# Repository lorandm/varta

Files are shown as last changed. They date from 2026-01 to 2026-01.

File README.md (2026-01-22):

# VARTA - Open Source Acoustic Drone Detector

**V**isual and **A**coustic **R**eal-**T**ime **A**lert System



[]()

---

> ⚠️ **ALPHA STATUS - READ BEFORE PROCEEDING**
>
> This project provides a **complete framework** for building an acoustic drone detector, but it is **not a plug-and-play solution**. Before this device will detect anything, you must:
>
> 1. **Collect training data** - Record drone audio samples in your environment
> 2. **Train the ML model** - Run the training pipeline on your collected data
> 3. **Assemble hardware** - Build the device from components (~$80-100)
> 4. **Calibrate and test** - Tune detection thresholds for your conditions
>
> **Current limitations:**
> - No pre-trained model included (you must train your own)
> - 4-microphone simultaneous capture needs firmware work (currently single-mic)
> - Detection performance is theoretical until field-validated
> - Hardware design is breadboard-ready, not a finished PCB
>
> This project is ideal for makers, researchers, and defense engineers who can contribute to development. It is **not ready** for non-technical end users expecting a finished product.
>
> **We welcome contributions** - especially training data, field test results, and firmware improvements.

---

## Overview

VARTA is an open-source, portable acoustic drone detection system designed to detect fiber optic controlled FPV drones that evade traditional RF-based detectors. Built for under $100 in components, it provides early warning capability for personnel in the field.

**Why VARTA exists:** RF drone detectors (like the BlueBird Chuyka) cannot detect fiber optic controlled drones because these drones don't emit radio signals. VARTA fills this critical gap using acoustic detection.

## Key Features

- **4-microphone beamforming array** for direction estimation
- **ML-based detection** using TensorFlow Lite for edge inference
- **4-8 second detection** at 200-500m range (environment dependent)
- **Visual + haptic + audio alerts** for high-noise environments
- **8+ hours battery life** on 2S 18650 pack
- **IP54 rated enclosure** (3D printable)
- **$80-100 total BOM cost**

## Specifications

| Parameter | Value |
|---|---|
| Detection Range | 200-500m (line of sight, low ambient noise) |
| Detection Time | 4-8 seconds |
| Direction Accuracy | ±15° azimuth |
| Power Supply | 7.4V (2S 18650) |
| Battery Life | 8+ hours continuous |
| Operating Temp | -20°C to +50°C |
| Enclosure Rating | IP54 |
| Weight | ~350g with battery |
| Dimensions | 140 x 80 x 45 mm |

## How It Works

### Detection Principle

Drone motors produce distinctive acoustic signatures in the 100-1000Hz range with characteristic harmonic patterns. VARTA uses:

1. **FFT Analysis** - Continuous spectral analysis looking for drone motor fundamentals (typically 150-400Hz) and their harmonics
2. **Beamforming** - Time-difference-of-arrival (TDOA) across 4 microphones estimates threat direction
3. **ML Classification** - TensorFlow Lite model distinguishes drones from environmental noise (vehicles, wind, wildlife)

### Limitations

- **Range decreases significantly** in high ambient noise (combat, vehicles, wind)
- **Cannot detect** drones with silenced/baffled motors at useful range
- **False positives** possible from other small motors, insects, etc.
- **No altitude estimation** - only azimuth direction
- **Requires line-of-sight acoustically** - terrain/structures block sound

## Hardware

### Bill of Materials

| Component | Quantity | Unit Cost | Notes |
|---|---|---|---|
| ESP32-S3-WROOM-1 | 1 | $8 | N16R8 variant recommended |
| INMP441 MEMS Microphone | 4 | $3 | I2S output |
| 0.96" OLED Display (SSD1306) | 1 | $4 | I2C, 128x64 |
| 2.4" TFT Display (ILI9341) | 1 | $8 | SPI, optional for waveform |
| Piezo Buzzer | 1 | $1 | 3-5V active |
| Vibration Motor | 1 | $2 | 3V coin type |
| WS2812B LED Ring (8 LED) | 1 | $3 | Direction indicator |
| 18650 Battery Holder (2S) | 1 | $3 | With BMS |
| 18650 Cells | 2 | $8 | 2500mAh+ recommended |
| TP4056 Charger Module | 1 | $1 | USB-C preferred |
| MT3608 Boost Converter | 1 | $1 | 5V for ESP32 |
| Power Switch | 1 | $1 | SPST |
| SMA Connectors (optional) | 4 | $4 | For external mics |
| PCB (custom) | 1 | $10 | JLCPCB/PCBWay |
| 3D Printed Enclosure | 1 | $5 | PLA or PETG |
| Misc (wires, screws, etc.) | - | $5 | - |

**Total: ~$85**

### Microphone Array Geometry

The 4 microphones are arranged in a square pattern with 50mm spacing:

```
        Front
          ↑
    [M1]-----[M2]
      |       |
      |   ●   |    ● = center/mounting point
      |       |
    [M4]-----[M3]
    
    Spacing: 50mm between adjacent mics
```

This geometry allows:
- Azimuth estimation via TDOA
- Reasonable angular resolution (~15°)
- Compact form factor

### Schematic

See `/hardware/kicad/` for full KiCad project files.

Key connections:
- **Microphones (I2S)**: All 4 INMP441 share SCK (GPIO14) and WS (GPIO15), individual SD pins (GPIO4, 5, 6, 7)
- **OLED Display (I2C)**: SDA (GPIO21), SCL (GPIO22)
- **TFT Display (SPI)**: MOSI (GPIO23), SCK (GPIO18), CS (GPIO5), DC (GPIO16), RST (GPIO17)
- **LED Ring**: Data (GPIO48)
- **Buzzer**: GPIO38
- **Vibration Motor**: GPIO39

## Firmware

### Building

Requires PlatformIO:

```bash
cd firmware
pio run
pio run --target upload
```

### Configuration

Edit `include/config.h`:

```c
// Detection thresholds (adjust based on field testing)
#define DETECTION_THRESHOLD_DB    65.0f   // Minimum signal level
#define CONFIDENCE_THRESHOLD      0.75f   // ML model confidence
#define ALERT_HOLDOFF_MS          2000    // Debounce alerts

// Hardware config
#define MIC_SPACING_MM            50.0f   // Physical mic spacing
#define SAMPLE_RATE               44100   // Audio sample rate
#define FFT_SIZE                  2048    // FFT window size
```

### Operating Modes

1. **SCAN** (default) - Continuous monitoring, LED ring shows ambient level
2. **ALERT** - Threat detected, LED shows direction, buzzer + vibration active
3. **MONITOR** - Display shows real-time spectrogram (debugging)
4. **CALIBRATE** - Ambient noise profiling for location

Button controls:
- **Short press**: Cycle display modes
- **Long press (3s)**: Enter calibration mode
- **Double press**: Mute audio alerts (haptic remains)

## Machine Learning

### Model Architecture

Lightweight CNN designed for ESP32-S3:

```
Input: 128 mel-frequency bands x 32 time frames (1 second)
├── Conv2D(16, 3x3) + ReLU + MaxPool
├── Conv2D(32, 3x3) + ReLU + MaxPool
├── Conv2D(64, 3x3) + ReLU + GlobalAvgPool
├── Dense(32) + ReLU + Dropout(0.3)
└── Dense(2) + Softmax → [no_drone, drone]

Parameters: ~45,000
Inference time: ~50ms on ESP32-S3
```

### Training Your Own Model

The default model provides baseline detection. For best results, train on data from your operational environment:

```bash
cd ml/training

# 1. Collect audio samples
python collect_samples.py --device your_mic --duration 300

# 2. Label samples (creates labels.csv)
python labeler.py --input samples/

# 3. Train model
python train.py --data samples/ --labels labels.csv --epochs 100

# 4. Convert to TFLite
python convert_tflite.py --model checkpoints/best.h5 --output ../models/

# 5. Generate C header for firmware
xxd -i models/drone_detector.tflite > ../firmware/src/model_data.h
```

### Training Data Requirements

For effective detection, collect:
- **Positive samples**: Various drone types at different distances/angles
- **Negative samples**: Environmental noise from deployment location
  - Wind, foliage rustling
  - Distant vehicles, aircraft
  - Voices, footsteps
  - Wildlife (birds, insects)
  - Combat sounds (if applicable)

Recommended: 2+ hours of each class, diverse conditions.

## Enclosure

### 3D Printing

Files in `/enclosure/`:
- `varta_body.stl` - Main enclosure
- `varta_lid.stl` - Top cover with mic ports
- `varta_clip.stl` - Belt/MOLLE clip

Print settings:
- Material: PETG recommended (better temperature resistance than PLA)
- Layer height: 0.2mm
- Infill: 20%
- Supports: Yes (for mic port overhangs)

### Weatherproofing

For IP54 rating:
1. Apply silicone sealant to lid seam
2. Install acoustic vent membrane over mic ports (e.g., Gore-Tex patch)
3. Seal cable glands with silicone

## Assembly

See [docs/ASSEMBLY.md](docs/ASSEMBLY.md) for step-by-step instructions with photos.

Quick overview:
1. Solder microphones to breakout boards (or direct to PCB)
2. Assemble main PCB with ESP32, power management
3. Wire display, buzzer, vibration motor
4. Install battery holder and cells
5. Mount PCB in enclosure
6. Position microphones in lid at correct spacing
7. Final wiring and close-up
8. Flash firmware and calibrate

## Field Use

### Pre-deployment

1. Power on and wait for self-test (LED sequence)
2. Verify GPS fix if equipped (optional module)
3. Run calibration in deployment location (30 seconds)
4. Verify alert function with test tone

### Operational Notes

- **Position**: Wear on shoulder/chest, mics facing likely threat direction
- **Ambient noise**: Detection range decreases significantly with background noise
- **Terrain**: Hills, buildings, vegetation attenuate sound - adjust expectations
- **Weather**: Wind is the enemy - seek shelter or accept reduced range
- **False alarms**: Initial deployments will have false positives; re-train model with local data

### Interpreting Alerts

LED ring indicates estimated threat direction:
- **Red LED position**: Threat azimuth (north = front, clockwise)
- **LED brightness**: Signal strength / confidence
- **Pulsing**: Active threat
- **Solid**: Recent detection, threat may have passed

## Roadmap

### Current Status (v0.1-alpha)

| Component | Status | Notes |
|---|---|---|
| Firmware architecture | ✅ Complete | Compiles, structured for expansion |
| Single-mic detection | ✅ Working | Basic audio capture and FFT |
| 4-mic simultaneous | 🔧 Partial | Needs I2S TDM implementation |
| Direction estimation | 🔧 Partial | Algorithm ready, needs 4-mic hardware |
| ML training pipeline | ✅ Complete | Collect, label, train, convert |
| Pre-trained model | ❌ Missing | Requires drone audio recordings |
| 3D enclosure | ✅ Complete | Parametric OpenSCAD source |
| Custom PCB | ❌ Not started | Current design uses dev boards |
| Field validation | ❌ Not done | No real-world test data yet |

### Priority Contributions Needed

1. **Training data** - Drone recordings at various distances/conditions
2. **4-channel I2S** - ESP32-S3 TDM mode or multi-I2S implementation  
3. **Field testing** - Build one, test it, report results
4. **PCB design** - Single board replacing dev board stack

### Future Ideas

- Bluetooth app for configuration and alerts
- Mesh networking between multiple units
- Integration with camera/thermal systems
- Solar power option for fixed installations
- LoRa for long-range alerting

## Contributing

Contributions welcome! Priority areas:
- Improved ML models trained on diverse drone types
- Alternative microphone arrays (linear, larger aperture)
- Integration with other sensor systems
- Mobile app for configuration/visualization
- Power optimization

See [CONTRIBUTING.md](CONTRIBUTING.md) for guidelines.

## License

Hardware: CERN-OHL-P-2.0
Software: MIT
Documentation: CC-BY-4.0

## Acknowledgments

This project builds on:
- ESP-IDF and Arduino frameworks
- TensorFlow Lite for Microcontrollers
- Countless open source audio processing libraries

## Disclaimer

VARTA is provided as-is for educational and research purposes. Detection performance varies significantly based on environmental conditions, drone types, and deployment scenario. This device is not a substitute for other protective measures. The authors assume no liability for use in any context.

---

*"In war, let your great object be victory, not lengthy campaigns."* - Sun Tzu

Built with urgency for those who need it.

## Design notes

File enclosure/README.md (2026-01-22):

# VARTA Enclosure

3D printable enclosure for the acoustic drone detector.

## Files

| File | Description |
|---|---|
| `enclosure.scad` | Parametric OpenSCAD source |
| `varta_body.stl` | Main body (pre-generated) |
| `varta_lid.stl` | Top cover with mic ports |
| `varta_clip.stl` | Belt/MOLLE attachment clip |

## Generating STL Files

If you need to modify the design, edit `enclosure.scad` and regenerate:

```bash
# Install OpenSCAD first
# Ubuntu: sudo apt install openscad
# Mac: brew install openscad

# Generate all parts
openscad -o varta_body.stl -D 'part="body"' enclosure.scad
openscad -o varta_lid.stl -D 'part="lid"' enclosure.scad  
openscad -o varta_clip.stl -D 'part="clip"' enclosure.scad
```

## Print Settings

### Recommended Settings

| Parameter | Value |
|---|---|
| Material | PETG (preferred) or PLA |
| Layer Height | 0.2mm |
| Infill | 20% |
| Perimeters | 3 |
| Top/Bottom Layers | 4 |
| Supports | Yes (for mic port overhangs) |

### Material Notes

**PETG** (Recommended)
- Better temperature resistance (-20°C to +70°C)
- More impact resistant
- Slight flexibility reduces cracking
- Harder to print (stringing)

**PLA**
- Easier to print
- More rigid
- Lower temperature tolerance (<50°C)
- Can warp in hot environments

**ABS**
- Good temperature resistance
- Requires enclosed printer
- More post-processing (fumes, warping)

## Assembly

### Hardware Needed

| Item | Quantity | Notes |
|---|---|---|
| M3 x 8mm screws | 4 | Lid attachment |
| M3 x 6mm screws | 4 | PCB mounting |
| M2 x 4mm screws | 4 | Mic board mounting |
| M3 nuts | 4 | For clip attachment |
| Silicone gasket (optional) | 1 | For IP54 sealing |

### Assembly Steps

1. **Prepare body**
   - Clean up any support material
   - Check screw boss threads (may need to tap)

2. **Install PCB standoffs**
   - Insert M3 screws from inside
   - Secure PCB with additional nuts or use self-tapping screws

3. **Mount components in lid**
   - Position microphone boards over ports
   - Secure with M2 screws
   - Install display bezel (if using)
   - Install LED ring

4. **Wire everything**
   - Connect microphones to main PCB
   - Connect display, LEDs, buzzer, vibration motor
   - Install battery holder

5. **Final assembly**
   - Apply silicone gasket to lid edge (optional)
   - Close lid and secure with M3 screws
   - Attach belt clip if needed

## Weatherproofing (IP54)

For outdoor use, add weatherproofing:

1. **Lid seal**
   - Apply 2mm silicone gasket to lid edge
   - Or use RTV silicone sealant

2. **Microphone ports**
   - Install acoustic vent membranes (e.g., GORE-TEX patches)
   - These allow sound through while blocking water
   - Available from speaker repair suppliers

3. **Display window**
   - Install clear acrylic or polycarbonate window
   - Seal edges with silicone

4. **USB port**
   - Install rubber plug when not charging
   - Or use waterproof USB connector

## Customization

### Key Parameters in OpenSCAD

```openscad
// Adjust these to fit your components:

mic_spacing = 50;       // Distance between mics
mic_hole_dia = 8;       // INMP441 breakout size
oled_width = 28;        // Display cutout
led_ring_dia = 32;      // LED ring size

// Overall size:
body_length = 140;
body_width = 80;
body_height = 35;
```

### Adding Features

To add new cutouts or mounting points:

1. Open `enclosure.scad` in OpenSCAD
2. Find the `body()` or `lid()` module
3. Add `translate()` and primitive shapes
4. Use `difference()` for cutouts
5. Preview and export STL

### Alternative Mounting Options

**Helmet mount**
- Design a curved plate to match helmet profile
- Use Velcro or screw attachment

**Vehicle mount**
- Add suction cup or magnetic base
- Consider vibration damping

**Pole mount**
- Design clamp attachment
- Good for perimeter monitoring

## Troubleshooting

### Parts Don't Fit

- Check `fit_tolerance` parameter (default 0.3mm)
- Your printer may need different value
- Print a test piece first

### Mic Ports Wrong Size

- Measure your actual breakout boards
- Adjust `mic_hole_dia` and `mic_mount_dia`

### Screws Don't Thread

- May need to tap holes with M3 tap
- Or use self-tapping screws
- Or heat-set inserts (recommended)

### Water Ingress

- Check gasket seating
- Verify acoustic membranes are installed
- Apply additional sealant to seams

## License

CERN-OHL-P-2.0 (Permissive Open Hardware License)

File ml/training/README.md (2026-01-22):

# VARTA ML Training Pipeline

This directory contains everything needed to train your own drone detection model.

## Requirements

```bash
pip install -r requirements.txt
```

## Quick Start

### 1. Collect Audio Samples

Record audio in environments where you'll deploy the detector:

```bash
# List available microphones
python collect_samples.py --list-devices

# Record for 5 minutes (press SPACE when you hear a drone)
python collect_samples.py --device 0 --duration 300 --output samples/
```

**Tips for good training data:**
- Record in actual deployment locations
- Include various distances (50m, 100m, 200m, 500m)
- Record different times of day (temperature affects sound propagation)
- Include various "negative" sounds: wind, vehicles, voices, wildlife
- Mark drone segments in real-time for accurate labels

### 2. Label Samples (if needed)

If you have unlabeled audio files, use the interactive labeler:

```bash
python labeler.py --input samples/

# Check labeling progress
python labeler.py --input samples/ --stats
```

### 3. Train Model

```bash
python train.py \
    --data samples/ \
    --labels samples/labels.csv \
    --epochs 100 \
    --output output/
```

Training will:
- Split data into train/val/test sets
- Train a lightweight CNN
- Save best model to `output/checkpoints/best.h5`
- Generate classification report

### 4. Convert to TFLite

```bash
python convert_tflite.py \
    --model output/checkpoints/best.h5 \
    --output ../models/ \
    --generate-header
```

This creates:
- `drone_detector_quant.tflite` - Quantized model for ESP32
- `model_data.h` - C header for firmware

### 5. Update Firmware

Copy the generated header to the firmware:

```bash
cp ../models/model_data.h ../firmware/src/model_data.h
```

Rebuild and flash:

```bash
cd ../firmware
pio run
pio run --target upload
```

## Training Data Guidelines

### Positive Samples (Drones)

Record various drone types at different distances and angles:

| Drone Type | Distance | Samples Needed |
|---|---|---|
| FPV racing | 50-200m  | 200+ segments  |
| FPV camera | 50-500m  | 200+ segments  |
| DJI-style  | 100-500m | 100+ segments  |

### Negative Samples (Not Drones)

Critical for reducing false positives:

| Sound Source | Samples Needed |
|---|---|
| Wind/foliage | 300+ segments  |
| Vehicles | 200+ segments  |
| Aircraft | 100+ segments  |
| Voices | 100+ segments  |
| Wildlife | 100+ segments  |
| Silence | 100+ segments  |
| Combat sounds| 200+ segments  |

### Data Augmentation

The training script applies automatic augmentation:
- Time shifting
- Noise injection
- Pitch shifting
- Time stretching

This helps with generalization but doesn't replace diverse real-world data.

## Model Architecture

The default model is a lightweight CNN designed for ESP32-S3:

```
Input: (32, 128, 1) - 32 time frames × 128 mel bins

Conv2D(16) → BatchNorm → ReLU → MaxPool
Conv2D(32) → BatchNorm → ReLU → MaxPool
Conv2D(64) → BatchNorm → ReLU → GlobalAvgPool
Dense(32) → ReLU → Dropout(0.3)
Dense(2) → Softmax

Total parameters: ~45,000
Inference time: ~50ms on ESP32-S3
```

## Customization

### Adjusting Detection Sensitivity

In `train.py`, modify:

```python
SAMPLE_RATE = 44100    # Match your hardware
N_MELS = 128           # Frequency resolution
DURATION = 1.0         # Detection window (seconds)
```

### Different Model Architectures

For better accuracy (larger model):
- Add more conv layers
- Increase filter counts
- Use attention mechanisms

For faster inference (smaller model):
- Reduce filter counts
- Use depthwise separable convolutions
- Decrease input resolution

### Transfer Learning

Start from a pre-trained audio model:

```python
# In train.py
from tensorflow.keras.applications import MobileNetV2

base_model = MobileNetV2(
    input_shape=(128, 128, 1),
    include_top=False,
    weights=None  # or use imagenet and adapt
)
```

## Troubleshooting

### Low Accuracy

- More training data needed (especially negatives)
- Try longer training (more epochs)
- Check class balance in dataset
- Verify audio quality (no clipping, correct sample rate)

### High False Positive Rate

- Add more negative samples from deployment environment
- Increase detection threshold in firmware
- Use multiple consecutive detections before alerting

### Model Too Large

- Enable quantization (default)
- Reduce model complexity
- Decrease input resolution (fewer mel bins)

### Inference Too Slow

- Use int8 quantization
- Reduce model depth
- Optimize ESP32-S3 settings (CPU frequency, etc.)

## Files

| File | Description |
|---|---|
| `collect_samples.py` | Real-time audio recording with marking |
| `labeler.py` | Interactive sample labeling tool |
| `train.py` | Model training script |
| `convert_tflite.py` | TFLite conversion for ESP32 |
| `requirements.txt` | Python dependencies |

## License

MIT License - see main project LICENSE

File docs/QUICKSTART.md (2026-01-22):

# VARTA Quick Start Guide

Get your acoustic drone detector running in under 2 hours.

## Prerequisites

**Tools needed:**
- Soldering iron
- Wire strippers
- Small screwdrivers
- 3D printer (or order prints)

**Software:**
- PlatformIO (VS Code extension or CLI)
- Python 3.8+ (for ML training)

## Step 1: Order Parts (5 minutes)

Order from the BOM in `/hardware/bom/BOM.csv`. Key items:
- ESP32-S3-DevKitC-1 (~$10)
- 4x INMP441 microphones (~$12)
- SSD1306 OLED display (~$4)
- WS2812B 8-LED ring (~$3)
- 2S 18650 battery pack (~$12)
- Power management boards (~$4)

**Total: ~$85**

## Step 2: Print Enclosure (2-4 hours)

Print from `/enclosure/` with PETG:
```bash
# Generate STLs if needed
openscad -o varta_body.stl -D 'part="body"' enclosure.scad
openscad -o varta_lid.stl -D 'part="lid"' enclosure.scad
```

Settings: 0.2mm layers, 20% infill, supports on.

## Step 3: Assemble (1-2 hours)

See `/docs/ASSEMBLY.md` for detailed instructions. Quick version:

1. **Power system:**
   - Battery holder → TP4056 charger → power switch → MT3608 boost (set to 5V) → ESP32

2. **Microphones:**
   - Wire all 4 INMP441 boards to shared I2S bus (SCK=GPIO14, WS=GPIO15)
   - Individual data lines to GPIO4, 5, 6, 7
   - Mount in lid with 50mm spacing

3. **Peripherals:**
   - OLED: SDA=GPIO21, SCL=GPIO22
   - LED ring: Data=GPIO48
   - Buzzer: GPIO38
   - Button: GPIO0

4. **Final assembly:**
   - Mount PCB in body
   - Connect all wiring
   - Install lid

## Step 4: Flash Firmware (5 minutes)

```bash
cd firmware
pip install platformio
pio run --target upload
pio device monitor  # Verify startup
```

You should see:
```
=== VARTA Acoustic Drone Detector ===
Initializing...
Initialization complete. Entering SCAN mode.
```

## Step 5: Calibrate (1 minute)

1. Power on device
2. Take to deployment location
3. Long-press button (3 seconds)
4. Wait 30 seconds for calibration
5. Done!

## Step 6: Train Custom Model (Optional, 1+ hours)

For best results, train on local audio:

```bash
cd ml/training
pip install -r requirements.txt

# Collect samples (press SPACE when drone present)
python collect_samples.py --device 0 --duration 300

# Train model
python train.py --data samples/ --labels samples/labels.csv --epochs 100

# Convert for ESP32
python convert_tflite.py --model output/checkpoints/best.h5 --output ../models/ --generate-header

# Update firmware
cp ../models/model_data.h ../firmware/src/model_data.h
cd ../firmware && pio run --target upload
```

## Usage

**Display modes:**
- SCAN: Normal monitoring (blue LED breathing)
- ALERT: Threat detected (red LED shows direction)
- MONITOR: Debug spectrogram view

**Controls:**
- Short press: Cycle display modes
- Double press: Mute audio (haptic only)
- Long press (3s): Calibration mode

**LED ring:**
- Blue breathing: Scanning
- Red direction: Threat detected (north = front)

## Troubleshooting

**No power:** Check battery, switch, boost converter output (should be 5V)

**Display blank:** Verify I2C address (0x3C or 0x3D), check wiring

**No detection:** Recalibrate in deployment location, check mic connections

**Too many false alarms:** Train custom model with local noise samples

## Need Help?

- Full docs: `/docs/ASSEMBLY.md`
- ML training: `/ml/training/README.md`
- Issues: GitHub Issues

---

*Built with urgency for those who need it.*

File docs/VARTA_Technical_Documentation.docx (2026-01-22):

VARTA

Visual and Acoustic Real-Time Alert System

Open Source Portable Acoustic Drone Detector

Designed to detect fiber optic controlled FPV drones

that evade traditional RF-based detection systems

Technical Documentation v1.0

January 2025

Hardware: CERN-OHL-P-2.0 | Software: MIT | Docs: CC-BY-4.0

# Table of Contents

# Executive Summary

VARTA is an open-source, portable acoustic drone detection system designed to address a critical gap in current drone defense: the inability of RF-based detectors to identify fiber optic controlled drones.

Traditional drone detection systems like the BlueBird Chuyka rely on detecting radio frequency emissions from drone control links. However, fiber optic controlled FPV drones transmit no RF signals, making them invisible to these systems. VARTA fills this gap using acoustic detection and machine learning classification.

## Key Capabilities

- 4-microphone beamforming array for direction estimation
- Machine learning classification using TensorFlow Lite on edge
- 200-500m detection range (environment dependent)
- Visual, audio, and haptic alerts for high-noise environments
- $80-100 total bill of materials cost
- Fully open source hardware and software

## Target Users

Infantry units, security personnel, and defensive operators who need portable, low-cost early warning against fiber optic FPV drones where RF detection is ineffective.

# Problem Statement

## The Fiber Optic Drone Threat

Fiber optic controlled FPV drones represent a significant evolution in drone warfare. By transmitting video and control signals through a thin fiber optic cable rather than radio waves, these systems achieve:

- Complete immunity to RF jamming and detection
- Zero electromagnetic signature during flight
- High-bandwidth, low-latency video transmission
- Resistance to electronic warfare countermeasures

## Current Detection Gap

RF-based drone detectors like the BlueBird Chuyka 2.0 ($460, 900-1800 MHz and 4860-6060 MHz scanning) are completely ineffective against fiber optic drones because there are no radio signals to detect.

Military-grade solutions exist (radar, sensor fusion) but are expensive ($50,000+), vehicle-mounted, and unavailable to frontline infantry units who face the most immediate threat.

## Market Opportunity

There is no commercially available portable detector in the $1,000-3,000 price range that can detect fiber optic drones. VARTA fills this gap using acoustic detection, the only viable passive detection method for infantry-portable systems.

# Technical Specifications

## System Overview

Parameter | Specification
Detection Range | 200-500m (line of sight, low ambient noise)
Detection Time | 4-8 seconds
Direction Accuracy | ±15° azimuth
Power Supply | 7.4V (2S 18650 Li-Ion)
Battery Life | 8+ hours continuous
Operating Temperature | -20°C to +50°C
Enclosure Rating | IP54 (dust and splash protected)
Weight | ~350g with battery
Dimensions | 140 x 80 x 45 mm

## Detection Methodology

VARTA uses three complementary detection techniques:

1. FFT Spectral Analysis: Continuous fast Fourier transform analysis identifies drone motor fundamentals (typically 150-400 Hz) and their characteristic harmonic patterns.

2. Beamforming: Time-difference-of-arrival (TDOA) across the 4-microphone square array estimates threat direction with ±15° accuracy.

3. ML Classification: A lightweight convolutional neural network running on the ESP32-S3 distinguishes drone signatures from environmental noise (vehicles, wind, wildlife).

## Hardware Architecture

The system is built around the ESP32-S3-WROOM-1 microcontroller with integrated Wi-Fi and Bluetooth, 16MB flash, and 8MB PSRAM for ML inference.

Component | Specification | Purpose
ESP32-S3-WROOM-1-N16R8 | 240 MHz dual-core, 16MB flash | Main processor, ML inference
INMP441 MEMS Microphone | I2S digital output, 4 units | Audio capture
SSD1306 OLED | 128x64 pixels, I2C | Status display
WS2812B LED Ring | 8 LEDs, 32mm diameter | Direction indicator
Piezo Buzzer | 3-5V active | Audio alert
Coin Vibration Motor | 3V DC | Haptic alert
18650 2S Pack | 7.4V, 5000mAh | Power source

# Machine Learning Model

## Architecture

The detection model is a lightweight convolutional neural network optimized for real-time inference on the ESP32-S3:

Input: 128 mel-frequency bands × 32 time frames (1 second of audio)

Layer 1: Conv2D (16 filters, 3×3) + BatchNorm + ReLU + MaxPool

Layer 2: Conv2D (32 filters, 3×3) + BatchNorm + ReLU + MaxPool

Layer 3: Conv2D (64 filters, 3×3) + BatchNorm + ReLU + GlobalAvgPool

Dense: 32 units + ReLU + Dropout (0.3)

Output: 2 classes (no_drone, drone) with softmax

Metric | Value
Total Parameters | ~45,000
Model Size (quantized) | ~50 KB
Inference Time | ~50 ms on ESP32-S3
Memory Usage | ~100 KB arena

## Training Pipeline

The project includes a complete training pipeline with Python scripts for data collection, labeling, training, and TensorFlow Lite conversion. Users train custom models on audio from their deployment environment for optimal performance.

# Bill of Materials

Total estimated cost: $83.92 USD

Component | Qty | Unit Cost | Total
ESP32-S3-DevKitC-1 | 1 | $9.99 | $9.99
INMP441 MEMS Microphone | 4 | $2.99 | $11.96
SSD1306 0.96" OLED | 1 | $3.99 | $3.99
WS2812B 8-LED Ring | 1 | $2.99 | $2.99
Piezo Buzzer | 1 | $0.99 | $0.99
Vibration Motor | 1 | $1.49 | $1.49
18650 2S Holder + BMS | 1 | $3.49 | $3.49
18650 Cells (2500mAh) | 2 | $4.99 | $9.98
TP4056 USB-C Charger | 1 | $1.99 | $1.99
MT3608 Boost Converter | 1 | $0.99 | $0.99
Switches, Buttons | 2 | $0.40 | $0.80
Resistors, Transistor | 4 | $0.10 | $0.40
Connectors, Headers | - | - | $2.00
Wire (22AWG + 26AWG) | - | - | $10.98
3D Printed Enclosure | 3 parts | - | $6.00
Hardware (screws, nuts) | - | - | $2.04
Miscellaneous | - | - | $13.98
| | TOTAL: | $83.92

# Limitations and Considerations

## Environmental Factors

- Detection range decreases significantly in high ambient noise (combat, vehicles, wind)
- Cannot detect drones with silenced or baffled motors at useful range
- False positives possible from other small motors, insects, distant vehicles
- Requires acoustic line-of-sight; terrain and structures attenuate sound

## Technical Limitations

- Azimuth direction only; no altitude estimation
- Model performance depends heavily on training data quality
- Initial deployment will have false positives until calibrated
- Not a substitute for other protective measures

## Recommended Mitigations

Deploy as part of layered defense with RF detection. Train custom ML models with audio from actual deployment environments. Use multiple units for overlapping coverage. Recalibrate when changing locations.

# Project Structure

Repository: github.com/[your-org]/varta

/firmware/ - ESP32-S3 firmware (PlatformIO)

/ml/training/ - Python ML training pipeline

/hardware/kicad/ - KiCad schematic files

/hardware/bom/ - Bill of materials

/enclosure/ - OpenSCAD 3D printable enclosure

/docs/ - Assembly instructions and documentation

## Getting Started

1. Clone repository and review documentation
2. Order components from BOM
3. 3D print enclosure (PETG recommended)
4. Assemble hardware per assembly guide
5. Flash firmware using PlatformIO
6. Collect training data in deployment environment
7. Train custom ML model
8. Deploy and calibrate

# Contributing and Roadmap

## Priority Contributions Needed

- Diverse drone audio training data from various types and distances
- Environmental noise samples from deployment scenarios
- Field testing reports with detection statistics
- Custom PCB design (currently uses dev boards)
- Mobile companion app for configuration

## Future Roadmap

- Multi-unit mesh networking for overlapping coverage
- Integration with external sensors (radar, thermal)
- OTA firmware updates
- Pre-trained models for common drone types
- Alternative form factors (helmet mount, vehicle mount)

# Conclusion

VARTA addresses a critical capability gap in drone defense. As fiber optic controlled drones become more prevalent, the inability of RF-based systems to detect them creates a significant vulnerability.

By leveraging acoustic detection, machine learning, and open-source collaboration, VARTA provides an affordable, deployable solution that can be built, modified, and improved by the community.

While acoustic detection has inherent limitations, it remains the only viable passive detection method for fiber optic drones at an infantry-portable price point. VARTA is designed to be one layer in a comprehensive defense strategy, not a complete solution.

The project is fully open source and welcomes contributions from the global defense and maker communities.

Licenses

Hardware: CERN-OHL-P-2.0 | Software: MIT | Documentation: CC-BY-4.0

VARTA Open Source Project

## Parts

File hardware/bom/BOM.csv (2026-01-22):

Category | Part Number | Description | Quantity | Unit Price USD | Total USD | Supplier | Notes
Microcontroller | ESP32-S3-DevKitC-1 | ESP32-S3 Development Board (N16R8) | 1 | 9.99 | 9.99 | Espressif/Mouser | 16MB Flash 8MB PSRAM
Microphone | INMP441 | I2S MEMS Microphone Breakout | 4 | 2.99 | 11.96 | AliExpress/Amazon | Digital I2S output
Display | SSD1306-096 | 0.96 inch OLED 128x64 I2C | 1 | 3.99 | 3.99 | Amazon/AliExpress | White or blue
LED | WS2812B-Ring8 | 8-LED NeoPixel Ring 32mm | 1 | 2.99 | 2.99 | Adafruit/AliExpress | Direction indicator
Audio | Piezo-Buzzer | Active Piezo Buzzer 3-5V | 1 | 0.99 | 0.99 | Amazon | 12mm diameter
Haptic | Coin-Vibration | 3V Coin Vibration Motor 10mm | 1 | 1.49 | 1.49 | Amazon/AliExpress | For haptic feedback
Power | 18650-Holder-2S | 2S 18650 Battery Holder with BMS | 1 | 3.49 | 3.49 | Amazon | Integrated protection
Power | 18650-Cell | Samsung 25R 18650 2500mAh | 2 | 4.99 | 9.98 | IMRbatteries | Or equivalent quality cells
Power | TP4056-USBC | USB-C Li-Ion Charger Module | 1 | 1.99 | 1.99 | Amazon/AliExpress | With protection circuit
Power | MT3608 | Adjustable Boost Converter | 1 | 0.99 | 0.99 | AliExpress | Set to 5V output
Switch | SPST-Slide | Slide Power Switch | 1 | 0.49 | 0.49 | Amazon | Panel mount
Switch | Tactile-6mm | Tactile Push Button 6mm | 1 | 0.29 | 0.29 | Amazon | Through-hole
Passive | Resistor-10K | 10K Ohm Resistor 1/4W | 2 | 0.05 | 0.10 | Any | For voltage divider
Passive | Resistor-1K | 1K Ohm Resistor 1/4W | 1 | 0.05 | 0.05 | Any | For transistor base
Semiconductor | 2N2222 | NPN Transistor TO-92 | 1 | 0.15 | 0.15 | Any | Motor driver
Connector | JST-PH-2P | JST PH 2.0mm 2-pin Connector | 4 | 0.25 | 1.00 | Amazon | Battery and motor
Connector | Header-Male | 2.54mm Male Pin Headers | 2 | 0.50 | 1.00 | Any | 40-pin strips
Wire | Silicone-22AWG | Silicone Wire 22AWG Assorted | 1 | 5.99 | 5.99 | Amazon | Red/Black/Colors
Wire | Silicone-26AWG | Silicone Wire 26AWG Assorted | 1 | 4.99 | 4.99 | Amazon | For signal lines
Enclosure | 3D-Print-Body | Main Body PETG 3D Print | 1 | 3.00 | 3.00 | Local/Online | ~50g material
Enclosure | 3D-Print-Lid | Lid with Mic Ports PETG | 1 | 2.00 | 2.00 | Local/Online | ~30g material
Enclosure | 3D-Print-Clip | Belt Clip PETG | 1 | 1.00 | 1.00 | Local/Online | ~15g material optional
Hardware | M3x8-Screw | M3 x 8mm Pan Head Screw | 8 | 0.10 | 0.80 | Amazon/McMaster | Stainless steel
Hardware | M3x6-Screw | M3 x 6mm Pan Head Screw | 4 | 0.10 | 0.40 | Amazon/McMaster | PCB mounting
Hardware | M2x4-Screw | M2 x 4mm Pan Head Screw | 8 | 0.08 | 0.64 | Amazon/McMaster | Mic board mounting
Hardware | M3-Nut | M3 Hex Nut | 4 | 0.05 | 0.20 | Amazon/McMaster | For clip attachment
Misc | Heat-Shrink | Heat Shrink Tubing Assortment | 1 | 3.99 | 3.99 | Amazon | Various sizes
Misc | Acoustic-Vent | PTFE Acoustic Membrane 10mm | 4 | 1.00 | 4.00 | Speaker repair supplier | Weatherproofing
Misc | Double-Tape | 3M VHB Double-Sided Tape | 1 | 5.99 | 5.99 | Amazon | Component mounting
TOTAL |  |  |  |  | 83.92
OPTIONAL UPGRADES
Display | ILI9341-TFT | 2.4 inch TFT SPI 320x240 | 1 | 7.99 | 7.99 | Amazon | Color spectrogram display
GPS | NEO-6M | u-blox NEO-6M GPS Module | 1 | 9.99 | 9.99 | Amazon | Position logging
Storage | MicroSD-Module | MicroSD Card Breakout SPI | 1 | 2.99 | 2.99 | Amazon | Data logging
Storage | MicroSD-16GB | 16GB MicroSD Card | 1 | 6.99 | 6.99 | Amazon | FAT32 formatted
Connector | SMA-Female | SMA Female PCB Connector | 4 | 1.50 | 6.00 | Amazon | External mic option
Case | Pelican-1010 | Pelican 1010 Micro Case | 1 | 16.99 | 16.99 | Amazon | Ruggedized alternative

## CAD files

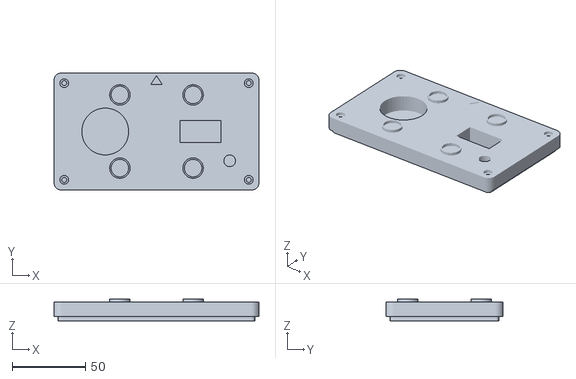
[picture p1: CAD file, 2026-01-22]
enclosure/varta_lid.stl
140.0 x 80.0 x 15.0

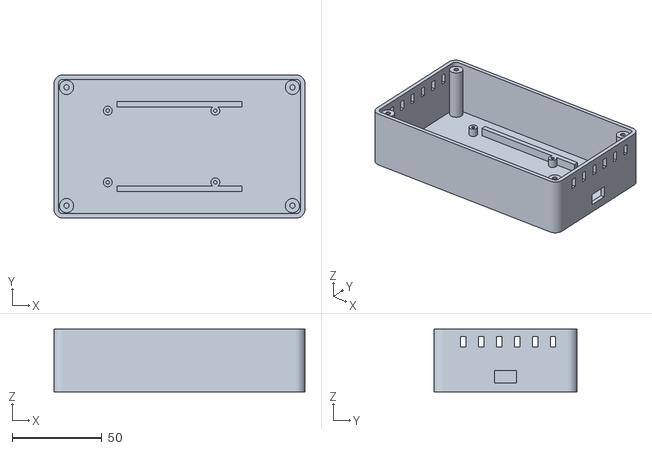
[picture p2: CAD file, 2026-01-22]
enclosure/varta_body.stl
140.0 x 80.0 x 35.0

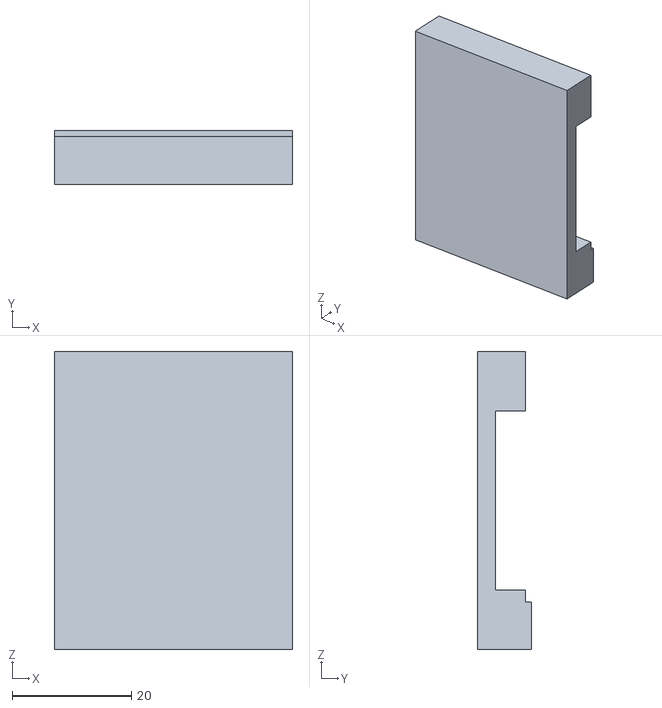
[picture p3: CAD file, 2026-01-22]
enclosure/varta_clip.stl
40.0 x 9.00 x 50.0

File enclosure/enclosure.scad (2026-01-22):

/*
 * VARTA - Acoustic Drone Detector Enclosure
 * OpenSCAD parametric design
 * 
 * Generate STL files:
 *   openscad -o varta_body.stl -D 'part="body"' enclosure.scad
 *   openscad -o varta_lid.stl -D 'part="lid"' enclosure.scad
 *   openscad -o varta_clip.stl -D 'part="clip"' enclosure.scad
 *   openscad -o varta_assembly.stl -D 'part="assembly"' enclosure.scad
 */

// Part selection
part = "assembly";  // "body", "lid", "clip", "assembly"

// =============================================================================
// PARAMETERS
// =============================================================================

// Overall dimensions
body_length = 140;      // mm
body_width = 80;        // mm
body_height = 35;       // mm
lid_height = 10;        // mm
wall_thickness = 2.5;   // mm
corner_radius = 5;      // mm

// Microphone array
mic_spacing = 50;       // mm between adjacent mics
mic_hole_dia = 8;       // mm (INMP441 breakout board)
mic_mount_dia = 12;     // mm

// Display cutout (OLED)
oled_width = 28;        // mm
oled_height = 15;       // mm
oled_offset_x = 30;     // mm from center
oled_offset_y = 0;      // mm from center

// LED ring cutout
led_ring_dia = 32;      // mm (8-LED ring)
led_ring_offset = -35;  // mm from center (toward rear)

// Button
button_dia = 8;         // mm
button_offset_x = 50;   // mm from center
button_offset_y = -20;  // mm from center

// USB port cutout
usb_width = 12;         // mm
usb_height = 7;         // mm

// Battery compartment
battery_length = 70;    // mm (2x 18650)
battery_width = 40;     // mm
battery_height = 20;    // mm

// Screw bosses
screw_boss_dia = 8;     // mm
screw_hole_dia = 3;     // mm (M3)
screw_depth = 10;       // mm

// Tolerances
fit_tolerance = 0.3;    // mm

// =============================================================================
// MODULES
// =============================================================================

module rounded_box(length, width, height, radius) {
    hull() {
        translate([radius, radius, 0])
            cylinder(r=radius, h=height, $fn=32);
        translate([length-radius, radius, 0])
            cylinder(r=radius, h=height, $fn=32);
        translate([radius, width-radius, 0])
            cylinder(r=radius, h=height, $fn=32);
        translate([length-radius, width-radius, 0])
            cylinder(r=radius, h=height, $fn=32);
    }
}

module screw_boss(height, outer_dia, hole_dia) {
    difference() {
        cylinder(d=outer_dia, h=height, $fn=24);
        translate([0, 0, -0.1])
            cylinder(d=hole_dia, h=height+0.2, $fn=16);
    }
}

module mic_port() {
    // Acoustic port with protective mesh holder
    union() {
        // Main hole
        cylinder(d=mic_hole_dia, h=wall_thickness*3, center=true, $fn=32);
        // Countersink for mesh
        translate([0, 0, wall_thickness/2])
            cylinder(d=mic_mount_dia, h=2, $fn=32);
    }
}

// =============================================================================
// BODY
// =============================================================================

module body() {
    difference() {
        // Outer shell
        rounded_box(body_length, body_width, body_height, corner_radius);
        
        // Inner cavity
        translate([wall_thickness, wall_thickness, wall_thickness])
            rounded_box(
                body_length - 2*wall_thickness,
                body_width - 2*wall_thickness,
                body_height,  // Open top
                corner_radius - wall_thickness
            );
        
        // USB port cutout (rear)
        translate([body_length - wall_thickness - 1, body_width/2 - usb_width/2, 5])
            cube([wall_thickness + 2, usb_width, usb_height]);
        
        // Ventilation slots (sides)
        for (y = [15, 25, 35, 45, 55, 65]) {
            // Left side
            translate([-1, y, body_height - 10])
                cube([wall_thickness + 2, 3, 6]);
            // Right side
            translate([body_length - wall_thickness - 1, y, body_height - 10])
                cube([wall_thickness + 2, 3, 6]);
        }
    }
    
    // Screw bosses (4 corners)
    boss_inset = corner_radius + 2;
    translate([boss_inset, boss_inset, wall_thickness])
        screw_boss(body_height - wall_thickness - 2, screw_boss_dia, screw_hole_dia);
    translate([body_length - boss_inset, boss_inset, wall_thickness])
        screw_boss(body_height - wall_thickness - 2, screw_boss_dia, screw_hole_dia);
    translate([boss_inset, body_width - boss_inset, wall_thickness])
        screw_boss(body_height - wall_thickness - 2, screw_boss_dia, screw_hole_dia);
    translate([body_length - boss_inset, body_width - boss_inset, wall_thickness])
        screw_boss(body_height - wall_thickness - 2, screw_boss_dia, screw_hole_dia);
    
    // Battery holder rails
    translate([body_length/2 - battery_length/2, body_width/2 - battery_width/2 - 5, wall_thickness])
        cube([battery_length, 3, 5]);
    translate([body_length/2 - battery_length/2, body_width/2 + battery_width/2 + 2, wall_thickness])
        cube([battery_length, 3, 5]);
    
    // PCB standoffs
    standoff_height = 5;
    standoff_dia = 5;
    standoff_hole = 2;
    
    // ESP32-S3 mounting points (adjust based on your PCB)
    for (pos = [
        [30, 20],
        [30, 60],
        [90, 20],
        [90, 60]
    ]) {
        translate([pos[0], pos[1], wall_thickness])
            screw_boss(standoff_height, standoff_dia, standoff_hole);
    }
}

// =============================================================================
// LID
// =============================================================================

module lid() {
    center_x = body_length / 2;
    center_y = body_width / 2;
    
    difference() {
        union() {
            // Main lid
            rounded_box(body_length, body_width, lid_height, corner_radius);
            
            // Inner lip for sealing
            translate([wall_thickness + fit_tolerance, wall_thickness + fit_tolerance, -3])
                rounded_box(
                    body_length - 2*(wall_thickness + fit_tolerance),
                    body_width - 2*(wall_thickness + fit_tolerance),
                    3,
                    corner_radius - wall_thickness - fit_tolerance
                );
        }
        
        // Microphone ports (square array, 50mm spacing)
        // M1: Front Left
        translate([center_x - mic_spacing/2, center_y + mic_spacing/2, 0])
            mic_port();
        // M2: Front Right  
        translate([center_x + mic_spacing/2, center_y + mic_spacing/2, 0])
            mic_port();
        // M3: Rear Right
        translate([center_x + mic_spacing/2, center_y - mic_spacing/2, 0])
            mic_port();
        // M4: Rear Left
        translate([center_x - mic_spacing/2, center_y - mic_spacing/2, 0])
            mic_port();
        
        // OLED display window
        translate([center_x + oled_offset_x - oled_width/2, 
                   center_y + oled_offset_y - oled_height/2, -1])
            cube([oled_width, oled_height, lid_height + 2]);
        
        // LED ring window
        translate([center_x + led_ring_offset, center_y, -1])
            cylinder(d=led_ring_dia, h=lid_height + 2, $fn=48);
        
        // Button hole
        translate([center_x + button_offset_x, center_y + button_offset_y, -1])
            cylinder(d=button_dia, h=lid_height + 2, $fn=24);
        
        // Screw holes (matching body bosses)
        boss_inset = corner_radius + 2;
        for (pos = [
            [boss_inset, boss_inset],
            [body_length - boss_inset, boss_inset],
            [boss_inset, body_width - boss_inset],
            [body_length - boss_inset, body_width - boss_inset]
        ]) {
            translate([pos[0], pos[1], -1])
                cylinder(d=screw_hole_dia + 0.5, h=lid_height + 2, $fn=16);
            // Countersink for screw head
            translate([pos[0], pos[1], lid_height - 2])
                cylinder(d=6, h=3, $fn=24);
        }
        
        // Direction indicator arrow (front marker)
        translate([center_x, body_width - 8, lid_height - 0.5])
            linear_extrude(1)
                polygon([[-4, 0], [4, 0], [0, 6]]);
    }
    
    // Mic mounting rings (raised)
    for (pos = [
        [center_x - mic_spacing/2, center_y + mic_spacing/2],
        [center_x + mic_spacing/2, center_y + mic_spacing/2],
        [center_x + mic_spacing/2, center_y - mic_spacing/2],
        [center_x - mic_spacing/2, center_y - mic_spacing/2]
    ]) {
        translate([pos[0], pos[1], lid_height])
            difference() {
                cylinder(d=mic_mount_dia + 2, h=2, $fn=32);
                translate([0, 0, -0.1])
                    cylinder(d=mic_mount_dia, h=2.2, $fn=32);
            }
    }
}
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

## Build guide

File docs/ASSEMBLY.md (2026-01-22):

# VARTA Assembly Guide

Step-by-step instructions to build your acoustic drone detector.

## Overview

**Estimated time:** 2-4 hours  
**Difficulty:** Intermediate (soldering required)  
**Tools needed:**
- Soldering iron + solder
- Wire strippers
- Small screwdrivers (Phillips, flat)
- Multimeter
- Hot glue gun (optional)
- 3D printer access (or order printed parts)

## Bill of Materials

### Electronics

| Component | Qty | Notes | Approx. Cost |
|---|-----|---|---|
| ESP32-S3-WROOM-1-N16R8 | 1 | DevKitC-1 recommended | $10 |
| INMP441 MEMS Microphone | 4 | I2S digital output | $12 |
| SSD1306 OLED Display | 1 | 0.96" 128x64 I2C | $4 |
| WS2812B LED Ring | 1 | 8 LED, ~32mm diameter | $3 |
| Active Piezo Buzzer | 1 | 3-5V | $1 |
| Coin Vibration Motor | 1 | 3V DC | $2 |
| 18650 Battery Holder | 1 | 2S with BMS | $3 |
| 18650 Cells | 2 | 2500mAh+ each | $8 |
| TP4056 USB-C Charger | 1 | With protection | $2 |
| MT3608 Boost Converter | 1 | Adjustable, set to 5V | $1 |
| Slide Switch | 1 | SPST | $0.50 |
| Tactile Button | 1 | 6mm | $0.25 |
| Resistors | 2 | 10K (voltage divider) | $0.10 |

**Subtotal electronics: ~$47**

### Hardware

| Item | Qty | Notes |
|---|-----|---|
| M3 x 8mm screws | 8 | Stainless preferred |
| M3 x 6mm screws | 4 | PCB mounting |
| M2 x 4mm screws | 8 | Mic boards |
| M3 nuts | 4 | For clip |
| Silicone wire (22-26 AWG) | 1m | Flexible |
| Heat shrink tubing | Assorted | |
| Double-sided tape | Small roll | Foam type |

### Enclosure

| Part | Qty | Notes |
|---|-----|---|
| Body (3D printed) | 1 | PETG recommended |
| Lid (3D printed) | 1 | PETG recommended |
| Clip (3D printed) | 1 | Optional |
| Acoustic vent membrane | 4 | 10mm diameter |
| Clear acrylic window | 1 | For display (optional) |

---

## Step 1: Prepare Components

### 1.1 Print Enclosure Parts

Print the following from `/enclosure/`:
- `varta_body.stl`
- `varta_lid.stl`
- `varta_clip.stl` (optional)

Settings: PETG, 0.2mm layers, 20% infill, supports on.

### 1.2 Test Electronics

Before soldering, verify each component works:

```
ESP32-S3: Connect USB, upload blink sketch
OLED: Connect I2C, run display test
Microphones: Connect one at a time, verify I2S signal
LED Ring: Connect data pin, run rainbow test
```

### 1.3 Prepare Wires

Cut and strip wires for:
- Power distribution (red/black, 22 AWG)
- I2S bus (4 colors, 26 AWG)
- I2C bus (2 colors, 26 AWG)
- Signal wires (various, 26 AWG)

---

## Step 2: Assemble Power System

### 2.1 Battery Holder

1. Solder wires to battery holder terminals
2. Connect BMS if not integrated
3. Verify polarity with multimeter

### 2.2 Charging Circuit

```
Battery+ ──→ TP4056 B+ ──→ (charging managed internally)
Battery- ──→ TP4056 B- 
            TP4056 OUT+ ──→ Power switch ──→ System+
            TP4056 OUT- ──→ System-
```

### 2.3 Voltage Regulation

```
System+ ──→ MT3608 IN+ ──→ MT3608 OUT+ ──→ 5V rail
System- ──→ MT3608 IN- ──→ MT3608 OUT- ──→ GND rail
```

**Important:** Adjust MT3608 output to exactly 5.0V before connecting ESP32!

### 2.4 Battery Monitoring

Create voltage divider for ADC:
```
Battery+ ──┬── 10K resistor ──┬── 10K resistor ──→ GND
           │                  │
           │                  └── To ESP32 GPIO1
           │
           └── (Also to power switch)
```

This gives 0-4.2V input → 0-2.1V to ADC (safe for 3.3V input).

---

## Step 3: Microphone Array

### 3.1 INMP441 Pinout

```
VDD ─── 3.3V
GND ─── GND
SD  ─── Data out (to ESP32)
WS  ─── Word Select (shared)
SCK ─── Serial Clock (shared)
L/R ─── Left/Right select
```

### 3.2 Wiring Diagram

```
              ┌─────────────────────────────────────────────┐
              │                 ESP32-S3                    │
              │                                             │
Mic1 ─SD──────┼──GPIO4                                      │
Mic2 ─SD──────┼──GPIO5                                      │
Mic3 ─SD──────┼──GPIO6                                      │
Mic4 ─SD──────┼──GPIO7                                      │
              │                                             │
All Mics ─WS──┼──GPIO15 (shared Word Select)               │
All Mics ─SCK─┼──GPIO14 (shared Serial Clock)              │
              │                                             │
All Mics ─VDD─┼──3.3V                                      │
All Mics ─GND─┼──GND                                       │
              └─────────────────────────────────────────────┘
```

### 3.3 L/R Channel Selection

For 4 independent channels, set L/R pins:
- Mic1: L/R → GND (Left channel)
- Mic2: L/R → VDD (Right channel)
- Mic3: L/R → GND
- Mic4: L/R → VDD

**Note:** Current firmware reads Mic1 only due to I2S limitations. Full 4-mic support requires I2S TDM mode or multiple I2S peripherals. See firmware TODO.

### 3.4 Mount Microphones in Lid

1. Position mic boards over the 4 ports
2. Ensure mic hole aligns with acoustic port
3. Secure with M2 screws
4. Apply acoustic vent membrane over each port (weatherproofing)

---

## Step 4: Main Board Assembly

### 4.1 ESP32-S3 Connections

| ESP32 Pin | Connection | Notes |
|---|---|---|
| GPIO4 | Mic1 SD | I2S Data |
| GPIO5 | Mic2 SD | I2S Data |
| GPIO6 | Mic3 SD | I2S Data |
| GPIO7 | Mic4 SD | I2S Data |
| GPIO14 | All Mics SCK | I2S Clock |
| GPIO15 | All Mics WS | I2S Word Select |
| GPIO21 | OLED SDA | I2C Data |
| GPIO22 | OLED SCL | I2C Clock |
| GPIO48 | LED Ring Data | WS2812B |
| GPIO38 | Buzzer | Active high |
| GPIO39 | Vibration Motor | Via transistor |
| GPIO0 | Button | Boot button, active low |
| GPIO1 | Battery ADC | Voltage divider |
| 5V | Power input | From MT3608 |
| GND | Ground | Common ground |

### 4.2 Display Wiring

```
OLED VCC ─── 3.3V
OLED GND ─── GND
OLED SDA ─── GPIO21
OLED SCL ─── GPIO22
```

### 4.3 LED Ring Wiring

```
LED VCC ─── 5V (needs full 5V for bright LEDs)
LED GND ─── GND
LED DIN ─── GPIO48
```

### 4.4 Alert Outputs

**Buzzer (direct drive OK for small buzzers):**
```
Buzzer+ ─── GPIO38
Buzzer- ─── GND
```

**Vibration Motor (use transistor for higher current):**
```
                    ┌─── Motor+ ─── 5V
2N2222 or           │
similar    Base ────┼─── 1K resistor ─── GPIO39
           Emitter ─┴─── GND
           Collector ─── Motor-
```

---

## Step 5: Final Assembly

### 5.1 Install Components in Body

1. **Battery holder:** Slide between guide rails, secure with hot glue or double-sided tape

2. **Charging board:** Mount near USB port cutout

3. **Power switch:** Mount in side wall (drill hole if needed)

4. **Main PCB/ESP32:** Mount on standoffs with M3 screws

5. **Boost converter:** Mount with double-sided tape, away from mics

### 5.2 Connect All Wiring

1. Connect power system (battery → charger → switch → boost → ESP32)
2. Connect I2S bus from lid mics to ESP32
3. Connect I2C bus (OLED)
4. Connect LED ring data
5. Connect buzzer and vibration motor
6. Connect button
7. Connect battery monitoring

### 5.3 Route and Secure Wires

- Use zip ties or hot glue to secure wires
- Keep power and signal wires separated
- Leave slack for lid opening/closing
- Ensure no wires block battery removal

### 5.4 Install Lid Components

Components mounted in lid:
- 4x Microphones (already installed)
- OLED display (position in window)
- LED ring (position in cutout)
- Button (if lid-mounted)

### 5.5 Close and Secure

1. Carefully close lid, guiding wires
2. Insert M3 screws in corners
3. Tighten evenly (don't over-tighten plastic)
4. Apply silicone gasket if weatherproofing

---

## Step 6: Flash Firmware

### 6.1 Install PlatformIO

```bash
pip install platformio
```

### 6.2 Build and Upload

```bash
cd firmware
pio run
pio run --target upload
```

### 6.3 Monitor Serial Output

```bash
pio device monitor
```

You should see:
```
=== VARTA Acoustic Drone Detector ===
Initializing...
I2S configured successfully
Display initialized
LEDs initialized
Loading ML model...
Model loaded. Input shape: [32, 128, 1]
Initialization complete. Entering SCAN mode.
```

---

## Step 7: Calibration

### 7.1 Initial Power-On

1. Insert charged batteries
2. Turn on power switch
3. Wait for startup sequence (LED sweep)
4. Display shows "VARTA READY"

### 7.2 Ambient Noise Calibration

1. Take device to deployment location
2. Ensure no drones present
3. Long-press button (3 seconds)
4. Wait 30 seconds while device records ambient noise
5. "CALIBRATION COMPLETE" displayed

### 7.3 Verify Operation

1. Device should show "SCAN" mode
2. LED ring shows subtle blue breathing
3. Display shows confidence near 0%
4. Test with drone recording (play on speaker) to verify detection

---

## Troubleshooting

### No Power

- Check battery charge (multimeter on battery terminals)
- Check power switch
- Verify MT3608 output is 5V
- Check for shorts

### Display Not Working

- Verify I2C address (0x3C default, some are 0x3D)
- Check SDA/SCL connections
- Try I2C scanner sketch

### No Audio Detection

- Check I2S wiring
- Verify mic boards have power (3.3V)
- Check L/R pin settings
- Try one mic at a time

### False Positives

- Re-run calibration in deployment environment
- Adjust DETECTION_THRESHOLD_DB in config.h
- Train custom ML model with local noise

### Short Battery Life

- Check for short circuits (feel for hot components)
- Reduce LED brightness
- Increase sleep intervals
- Use higher capacity cells

---

## Maintenance

### Regular Checks

- Clean mic ports (blow out dust)
- Check battery connections
- Verify gaskets if weatherproofed
- Re-calibrate if moving to new location

### Battery Care

- Charge before extended storage
- Don't discharge below 6.0V
- Replace cells every 2-3 years
- Store at ~50% charge if not using

---

## Safety Notes

- Li-ion batteries can be dangerous if damaged or short-circuited
- Use protected cells with built-in BMS
- Don't charge unattended
- Don't expose to extreme heat
- Dispose of batteries properly

---

**Congratulations!** Your VARTA drone detector is ready for field testing.

For training a custom ML model, see `ml/training/README.md`.

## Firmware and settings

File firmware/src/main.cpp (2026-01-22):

/**
 * VARTA - Acoustic Drone Detector
 * Main Firmware
 * 
 * ESP32-S3 based acoustic detection system for fiber optic FPV drones.
 * Uses 4-microphone array with ML-based classification.
 * 
 * License: MIT
 */

#include <Arduino.h>
#include <driver/i2s.h>
#include <Wire.h>
#include <Adafruit_GFX.h>
#include <Adafruit_SSD1306.h>
#include <Adafruit_NeoPixel.h>
#include <arduinoFFT.h>
#include <TensorFlowLite_ESP32.h>
#include "tensorflow/lite/micro/all_ops_resolver.h"
#include "tensorflow/lite/micro/micro_interpreter.h"
#include "tensorflow/lite/schema/schema_generated.h"

#include "config.h"
#include "model_data.h"
#include "audio_processor.h"
#include "direction_estimator.h"
#include "alert_manager.h"

// =============================================================================
// GLOBAL OBJECTS
// =============================================================================

// Display
Adafruit_SSD1306 display(OLED_WIDTH, OLED_HEIGHT, &Wire, -1);

// LED Ring
Adafruit_NeoPixel ledRing(LED_COUNT, LED_PIN, NEO_GRB + NEO_KHZ800);

// Audio Processing
AudioProcessor audioProcessor;
DirectionEstimator directionEstimator;
AlertManager alertManager;

// TensorFlow Lite
const tflite::Model* model = nullptr;
tflite::MicroInterpreter* interpreter = nullptr;
TfLiteTensor* input = nullptr;
TfLiteTensor* output = nullptr;
uint8_t tensorArena[MODEL_ARENA_SIZE];
tflite::AllOpsResolver resolver;

// State
enum SystemState {
    STATE_INIT,
    STATE_SCAN,
    STATE_ALERT,
    STATE_MONITOR,
    STATE_CALIBRATE,
    STATE_LOW_BATTERY,
    STATE_ERROR
};

SystemState currentState = STATE_INIT;
volatile bool newAudioReady = false;
float currentConfidence = 0.0f;
float currentDirection = 0.0f;
int detectionCount = 0;
unsigned long lastDetectionTime = 0;
unsigned long lastAlertTime = 0;
bool audioMuted = false;

// Audio buffers
float audioBuffer[4][FFT_SIZE];         // Per-microphone buffers
float melSpectrogram[MEL_BINS * SPEC_TIME_FRAMES];
int spectrogramIndex = 0;

// =============================================================================
// FORWARD DECLARATIONS
// =============================================================================

void setupI2S();
void setupDisplay();
void setupLEDs();
void setupModel();
void readAudioSamples();
void processAudio();
float runInference();
void updateDisplay();
void updateLEDs(float direction, float confidence);
void handleButton();
float readBatteryVoltage();
void enterCalibrationMode();

// =============================================================================
// SETUP
// =============================================================================

void setup() {
    Serial.begin(SERIAL_BAUD);
    Serial.println("\n=== VARTA Acoustic Drone Detector ===");
    Serial.println("Initializing...");

    // Initialize GPIO
    pinMode(BUZZER_PIN, OUTPUT);
    pinMode(VIBRATION_PIN, OUTPUT);
    pinMode(BUTTON_PIN, INPUT_PULLUP);
    pinMode(BATTERY_ADC_PIN, INPUT);

    // Startup indication
    digitalWrite(BUZZER_PIN, HIGH);
    delay(100);
    digitalWrite(BUZZER_PIN, LOW);

    // Initialize subsystems
    setupDisplay();
    setupLEDs();
    setupI2S();
    setupModel();

    // Initialize processors
    audioProcessor.begin(SAMPLE_RATE, FFT_SIZE, MEL_BINS);
    directionEstimator.begin(MIC_SPACING_MM, SPEED_OF_SOUND, SAMPLE_RATE);
    alertManager.begin(BUZZER_PIN, VIBRATION_PIN);

    // Self-test LED sequence
    for (int i = 0; i < LED_COUNT; i++) {
        ledRing.setPixelColor(i, ledRing.Color(0, 50, 0));
        ledRing.show();
        delay(100);
        ledRing.setPixelColor(i, 0);
    }
    ledRing.show();

    currentState = STATE_SCAN;
    Serial.println("Initialization complete. Entering SCAN mode.");

    display.clearDisplay();
    display.setTextSize(1);
    display.setTextColor(SSD1306_WHITE);
    display.setCursor(0, 0);
    display.println("VARTA READY");
    display.println("Mode: SCAN");
    display.display();
}

// =============================================================================
// MAIN LOOP
// =============================================================================

void loop() {
    static unsigned long lastProcessTime = 0;
    unsigned long currentTime = millis();

    // Handle user input
    handleButton();

    // Check battery
    float batteryVoltage = readBatteryVoltage();
    if (batteryVoltage < BATTERY_CRITICAL_VOLTAGE) {
        currentState = STATE_LOW_BATTERY;
    }

    // State machine
    switch (currentState) {
        case STATE_SCAN:
        case STATE_ALERT:
            // Read and process audio at regular intervals
            if (currentTime - lastProcessTime >= (HOP_SIZE * 1000 / SAMPLE_RATE)) {
                lastProcessTime = currentTime;
                
                readAudioSamples();
                processAudio();
                
                // Run ML inference
                currentConfidence = runInference();
                
                // Estimate direction if detection
                if (currentConfidence >= CONFIDENCE_THRESHOLD) {
                    currentDirection = directionEstimator.estimateDirection(
                        audioBuffer[0], audioBuffer[1], 
                        audioBuffer[2], audioBuffer[3], 
                        FFT_SIZE
                    );
                    
                    detectionCount++;
                    lastDetectionTime = currentTime;
                    
                    #if DEBUG_PRINT_DETECTION
                    Serial.printf("DETECTION: conf=%.2f dir=%.1f° count=%d\n", 
                                  currentConfidence, currentDirection, detectionCount);
                    #endif
                }
                
                // Check if we should alert
                if (detectionCount >= MIN_DETECTIONS_FOR_ALERT && 
                    currentTime - lastAlertTime >= ALERT_HOLDOFF_MS) {
                    
                    currentState = STATE_ALERT;
                    lastAlertTime = currentTime;
                    
                    if (!audioMuted) {
                        alertManager.triggerAlert(ALERT_DURATION_MS);
                    } else {
                        alertManager.triggerHapticOnly(ALERT_DURATION_MS);
                    }
                    
                    Serial.println("*** ALERT: DRONE DETECTED ***");
                }
                
                // Decay detection count over time
                if (currentTime - lastDetectionTime > DETECTION_WINDOW_MS) {
                    detectionCount = 0;
                    if (currentState == STATE_ALERT) {
                        currentState = STATE_SCAN;
                    }
                }
            }
            
            updateDisplay();
            updateLEDs(currentDirection, currentConfidence);
            break;

        case STATE_MONITOR:
            // Real-time spectrogram display mode
            if (currentTime - lastProcessTime >= (HOP_SIZE * 1000 / SAMPLE_RATE)) {
                lastProcessTime = currentTime;
                readAudioSamples();
                processAudio();
                // Display spectrogram on TFT if available
            }
            updateDisplay();
            break;

        case STATE_CALIBRATE:
            enterCalibrationMode();
            currentState = STATE_SCAN;
            break;

        case STATE_LOW_BATTERY:
            display.clearDisplay();
            display.setCursor(0, 20);
            display.setTextSize(2);
            display.println("LOW BATT");
            display.setTextSize(1);
            display.printf("%.1fV", batteryVoltage);
            display.display();
            
            ledRing.fill(ledRing.Color(50, 0, 0));
            ledRing.show();
            
            delay(1000);
            break;

        case STATE_ERROR:
            display.clearDisplay();
            display.setCursor(0, 20);
            display.setTextSize(2);
            display.println("ERROR");
            display.display();
            delay(1000);
            break;

        default:
            break;
    }

    // Alert manager update
    alertManager.update();
}

// =============================================================================
// I2S AUDIO SETUP
// =============================================================================

void setupI2S() {
    Serial.println("Configuring I2S...");

    i2s_config_t i2s_config = {
        .mode = (i2s_mode_t)(I2S_MODE_MASTER | I2S_MODE_RX),
        .sample_rate = SAMPLE_RATE,
        .bits_per_sample = (i2s_bits_per_sample_t)SAMPLE_BITS,
        .channel_format = I2S_CHANNEL_FMT_ONLY_LEFT,
        .communication_format = I2S_COMM_FORMAT_STAND_I2S,
        .intr_alloc_flags = ESP_INTR_FLAG_LEVEL1,
        .dma_buf_count = 8,
        .dma_buf_len = FFT_SIZE,
        .use_apll = true,
        .tx_desc_auto_clear = false,
        .fixed_mclk = 0
    };

    i2s_pin_config_t pin_config = {
        .bck_io_num = I2S_SCK_PIN,
        .ws_io_num = I2S_WS_PIN,
        .data_out_num = I2S_PIN_NO_CHANGE,
        .data_in_num = I2S_SD_PIN_MIC1  // Primary mic for now
    };

    esp_err_t err = i2s_driver_install(I2S_NUM_0, &i2s_config, 0, NULL);
    if (err != ESP_OK) {
        Serial.printf("I2S driver install failed: %d\n", err);
        currentState = STATE_ERROR;
        return;
    }

    err = i2s_set_pin(I2S_NUM_0, &pin_config);
    if (err != ESP_OK) {
        Serial.printf("I2S set pin failed: %d\n", err);
        currentState = STATE_ERROR;
        return;
    }

    Serial.println("I2S configured successfully");
}

// =============================================================================
// DISPLAY SETUP
// =============================================================================

void setupDisplay() {
    Serial.println("Initializing display...");

    Wire.begin(OLED_SDA_PIN, OLED_SCL_PIN);

    if (!display.begin(SSD1306_SWITCHCAPVCC, OLED_ADDRESS)) {
        Serial.println("SSD1306 allocation failed");
        currentState = STATE_ERROR;
        return;
    }

    display.clearDisplay();
    display.setTextSize(1);
    display.setTextColor(SSD1306_WHITE);
    display.setCursor(0, 0);
    display.println("VARTA v1.0");
    display.println("Initializing...");
    display.display();

    Serial.println("Display initialized");
}

// =============================================================================
// LED SETUP
// =============================================================================

void setupLEDs() {
    Serial.println("Initializing LEDs...");
    ledRing.begin();
    ledRing.setBrightness(LED_BRIGHTNESS);
    ledRing.show();
    Serial.println("LEDs initialized");
}

// =============================================================================
// ML MODEL SETUP
// =============================================================================

void setupModel() {
    Serial.println("Loading ML model...");

    model = tflite::GetModel(drone_detector_tflite);
    if (model->version() != TFLITE_SCHEMA_VERSION) {
        Serial.printf("Model schema mismatch: %d vs %d\n", 
                      model->version(), TFLITE_SCHEMA_VERSION);
        currentState = STATE_ERROR;
        return;
    }

    interpreter = new tflite::MicroInterpreter(
        model, resolver, tensorArena, MODEL_ARENA_SIZE
    );

    if (interpreter->AllocateTensors() != kTfLiteOk) {
        Serial.println("AllocateTensors() failed");
        currentState = STATE_ERROR;
        return;
    }

    input = interpreter->input(0);
    output = interpreter->output(0);

    Serial.printf("Model loaded. Input shape: [%d, %d, %d]\n",
                  input->dims->data[1], input->dims->data[2], input->dims->data[3]);
    Serial.printf("Arena used: %d bytes\n", interpreter->arena_used_bytes());
}

// =============================================================================
// AUDIO READING
// =============================================================================

void readAudioSamples() {
    size_t bytesRead = 0;
    int32_t rawSamples[FFT_SIZE];

    // Read from I2S
    esp_err_t result = i2s_read(I2S_NUM_0, rawSamples, sizeof(rawSamples), 
                                 &bytesRead, portMAX_DELAY);

    if (result == ESP_OK && bytesRead > 0) {
        int samplesRead = bytesRead / sizeof(int32_t);
        
        // Convert to float and normalize
        for (int i = 0; i < samplesRead && i < FFT_SIZE; i++) {
            // INMP441 is 24-bit in 32-bit frame, left-aligned
            float sample = (float)(rawSamples[i] >> 8) / 8388608.0f;  // Normalize to [-1, 1]
            audioBuffer[0][i] = sample;
        }
        
        // TODO: Read other 3 microphones via I2S multiplexing or additional I2S ports
        // For prototype, copy mic 1 to others (direction estimation won't work)
        memcpy(audioBuffer[1], audioBuffer[0], FFT_SIZE * sizeof(float));
        memcpy(audioBuffer[2], audioBuffer[0], FFT_SIZE * sizeof(float));
        memcpy(audioBuffer[3], audioBuffer[0], FFT_SIZE * sizeof(float));
    }
}

// =============================================================================
// AUDIO PROCESSING
// =============================================================================

void processAudio() {
    // Compute mel spectrogram from mic 1
    float melFrame[MEL_BINS];
    audioProcessor.computeMelSpectrogram(audioBuffer[0], FFT_SIZE, melFrame);

    // Add to rolling spectrogram buffer
    memcpy(&melSpectrogram[spectrogramIndex * MEL_BINS], melFrame, 
           MEL_BINS * sizeof(float));
    
    spectrogramIndex = (spectrogramIndex + 1) % SPEC_TIME_FRAMES;
}

// =============================================================================
// ML INFERENCE
// =============================================================================

float runInference() {
    if (interpreter == nullptr || input == nullptr || output == nullptr) {
        return 0.0f;
    }

    // Copy spectrogram to model input (normalize to 0-1 range)
    float* inputData = input->data.f;
    for (int t = 0; t < SPEC_TIME_FRAMES; t++) {
        int srcIndex = (spectrogramIndex + t) % SPEC_TIME_FRAMES;
        for (int f = 0; f < MEL_BINS; f++) {
            float val = melSpectrogram[srcIndex * MEL_BINS + f];
            // Normalize dB to 0-1 range (assuming -80 to 0 dB)
            val = (val + 80.0f) / 80.0f;
            val = constrain(val, 0.0f, 1.0f);
            inputData[t * MEL_BINS + f] = val;
        }
    }

    // Run inference
    if (interpreter->Invoke() != kTfLiteOk) {
        Serial.println("Inference failed");
        return 0.0f;
    }

    // Get drone class probability
    float* outputData = output->data.f;
    float droneConfidence = outputData[DRONE_CLASS_INDEX];

    return droneConfidence;
}

// =============================================================================
// DISPLAY UPDATE
// =============================================================================

void updateDisplay() {
    static unsigned long lastDisplayUpdate = 0;
    if (millis() - lastDisplayUpdate < 100) return;  // 10 Hz update
    lastDisplayUpdate = millis();

    display.clearDisplay();
    display.setTextSize(1);
    display.setCursor(0, 0);

    // Status line
    display.print("VARTA ");
    switch (currentState) {
        case STATE_SCAN:    display.println("SCAN"); break;
        case STATE_ALERT:   display.println("ALERT!"); break;
        case STATE_MONITOR: display.println("MONITOR"); break;
        default:            display.println("---"); break;
    }

    // Confidence bar
    display.setCursor(0, 12);
    display.print("Conf: ");
    int barWidth = (int)(currentConfidence * 60);
    display.drawRect(35, 12, 62, 8, SSD1306_WHITE);
    display.fillRect(36, 13, barWidth, 6, SSD1306_WHITE);

    // Direction
    display.setCursor(0, 24);
    display.printf("Dir: %.0f%c", currentDirection, 0xF8);  // Degree symbol

    // Detection count
    display.setCursor(0, 36);
    display.printf("Det: %d/%d", detectionCount, MIN_DETECTIONS_FOR_ALERT);

    // Battery
    float batt = readBatteryVoltage();
    display.setCursor(0, 48);
    display.printf("Batt: %.1fV", batt);
    if (audioMuted) {
        display.setCursor(80, 48);
        display.print("MUTE");
    }

    // Alert indicator
    if (currentState == STATE_ALERT) {
        display.fillRect(100, 0, 28, 10, SSD1306_WHITE);
        display.setTextColor(SSD1306_BLACK);
        display.setCursor(102, 1);
        display.print("!!!");
        display.setTextColor(SSD1306_WHITE);
    }

    display.display();
}

// =============================================================================
// LED UPDATE
// =============================================================================

void updateLEDs(float direction, float confidence) {
    ledRing.clear();

    if (currentState == STATE_ALERT) {
        // Map direction (0-360) to LED index (0-7)
        // Assuming LED 0 is "forward"
        int ledIndex = ((int)((direction + 22.5f) / 45.0f)) % LED_COUNT;
        
        // Intensity based on confidence
        int intensity = (int)(confidence * 255);
        
        // Primary LED (threat direction)
        ledRing.setPixelColor(ledIndex, ledRing.Color(intensity, 0, 0));
        
        // Adjacent LEDs at lower intensity
        int prev = (ledIndex - 1 + LED_COUNT) % LED_COUNT;
        int next = (ledIndex + 1) % LED_COUNT;
        ledRing.setPixelColor(prev, ledRing.Color(intensity / 3, 0, 0));
        ledRing.setPixelColor(next, ledRing.Color(intensity / 3, 0, 0));
        
    } else if (currentState == STATE_SCAN) {
        // Ambient level indicator - subtle blue pulse
        static uint8_t breathe = 0;
        static int8_t breatheDir = 1;
        breathe += breatheDir * 2;
        if (breathe >= 30 || breathe <= 0) breatheDir = -breatheDir;
        
        for (int i = 0; i < LED_COUNT; i++) {
            ledRing.setPixelColor(i, ledRing.Color(0, 0, breathe));
        }
    }

    ledRing.show();
}

// =============================================================================
// BUTTON HANDLING
// =============================================================================

void handleButton() {
    static unsigned long buttonPressTime = 0;
    static bool buttonWasPressed = false;
    static int quickPressCount = 0;
    static unsigned long lastQuickPress = 0;

    bool buttonPressed = (digitalRead(BUTTON_PIN) == LOW);

    if (buttonPressed && !buttonWasPressed) {
        // Button just pressed
        buttonPressTime = millis();
        buttonWasPressed = true;
    }
    else if (!buttonPressed && buttonWasPressed) {
        // Button just released
        unsigned long pressDuration = millis() - buttonPressTime;
        buttonWasPressed = false;

        if (pressDuration >= 3000) {
            // Long press - calibration mode
            Serial.println("Long press - entering calibration");
            currentState = STATE_CALIBRATE;
        }
        else if (pressDuration >= 50) {
            // Short press
            if (millis() - lastQuickPress < 500) {
                quickPressCount++;
            } else {
                quickPressCount = 1;
            }
            lastQuickPress = millis();

            if (quickPressCount >= 2) {
                // Double press - toggle mute
                audioMuted = !audioMuted;
                Serial.printf("Audio mute: %s\n", audioMuted ? "ON" : "OFF");
                quickPressCount = 0;
            }
        }
    }

    // Single press action (after timeout)
    if (quickPressCount == 1 && millis() - lastQuickPress > 500) {
        // Cycle display mode
        if (currentState == STATE_SCAN) {
            currentState = STATE_MONITOR;
        } else if (currentState == STATE_MONITOR) {
            currentState = STATE_SCAN;
        }
        Serial.printf("Mode changed to: %d\n", currentState);
        quickPressCount = 0;
    }
}

// =============================================================================
// BATTERY MONITORING
// =============================================================================

float readBatteryVoltage() {
    int adcValue = analogRead(BATTERY_ADC_PIN);
    float voltage = (adcValue / 4095.0f) * 3.3f * BATTERY_DIVIDER;
    return voltage;
}

// =============================================================================
// CALIBRATION
// =============================================================================

void enterCalibrationMode() {
    Serial.println("=== CALIBRATION MODE ===");
    
    display.clearDisplay();
    display.setCursor(0, 0);
    display.println("CALIBRATING...");
    display.println("Keep quiet for");
    display.println("30 seconds");
    display.display();

    // Collect ambient noise profile
    float noiseFloor[MEL_BINS] = {0};
    int sampleCount = 0;
    unsigned long startTime = millis();

    while (millis() - startTime < 30000) {
        readAudioSamples();
        
        float melFrame[MEL_BINS];
        audioProcessor.computeMelSpectrogram(audioBuffer[0], FFT_SIZE, melFrame);
        
        // Running average
        for (int i = 0; i < MEL_BINS; i++) {
            noiseFloor[i] = (noiseFloor[i] * sampleCount + melFrame[i]) / (sampleCount + 1);
        }
        sampleCount++;

        // Progress indicator
        int progress = (millis() - startTime) / 300;  // 0-100
        display.fillRect(0, 50, progress * 1.28, 10, SSD1306_WHITE);
        display.display();

        delay(10);
    }

    // Store noise profile
    audioProcessor.setNoiseFloor(noiseFloor);

    display.clearDisplay();
    display.setCursor(0, 20);
    display.println("CALIBRATION");
    display.println("COMPLETE");
    display.display();
    delay(2000);

    Serial.println("Calibration complete");
}

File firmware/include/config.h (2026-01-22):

/**
 * VARTA - Acoustic Drone Detector
 * Configuration Header
 * 
 * Adjust these values based on your hardware and deployment environment.
 */

#ifndef CONFIG_H
#define CONFIG_H

// =============================================================================
// HARDWARE CONFIGURATION
// =============================================================================

// ESP32-S3 Pin Assignments
// Microphones (I2S) - INMP441
#define I2S_SCK_PIN         14      // Serial Clock (shared)
#define I2S_WS_PIN          15      // Word Select (shared)
#define I2S_SD_PIN_MIC1     4       // Serial Data - Mic 1 (Front Left)
#define I2S_SD_PIN_MIC2     5       // Serial Data - Mic 2 (Front Right)
#define I2S_SD_PIN_MIC3     6       // Serial Data - Mic 3 (Rear Right)
#define I2S_SD_PIN_MIC4     7       // Serial Data - Mic 4 (Rear Left)

// OLED Display (I2C) - SSD1306
#define OLED_SDA_PIN        21
#define OLED_SCL_PIN        22
#define OLED_WIDTH          128
#define OLED_HEIGHT         64
#define OLED_ADDRESS        0x3C

// TFT Display (SPI) - ILI9341 (optional)
#define TFT_ENABLED         false
#define TFT_MOSI_PIN        23
#define TFT_SCK_PIN         18
#define TFT_CS_PIN          5
#define TFT_DC_PIN          16
#define TFT_RST_PIN         17

// LED Ring - WS2812B
#define LED_PIN             48
#define LED_COUNT           8
#define LED_BRIGHTNESS      50      // 0-255

// Alert Outputs
#define BUZZER_PIN          38
#define VIBRATION_PIN       39

// User Input
#define BUTTON_PIN          0       // Boot button

// Battery Monitoring
#define BATTERY_ADC_PIN     1
#define BATTERY_DIVIDER     2.0f    // Voltage divider ratio

// =============================================================================
// AUDIO CONFIGURATION
// =============================================================================

#define SAMPLE_RATE         44100   // Hz
#define SAMPLE_BITS         32      // I2S bit depth
#define FFT_SIZE            2048    // Must be power of 2
#define HOP_SIZE            512     // FFT hop (overlap = FFT_SIZE - HOP_SIZE)
#define MEL_BINS            128     // Mel frequency bins
#define SPEC_TIME_FRAMES    32      // Time frames for ML input (1 second)

// Microphone array geometry
#define MIC_SPACING_MM      50.0f   // Distance between adjacent mics
#define SPEED_OF_SOUND      343.0f  // m/s at 20°C

// =============================================================================
// DETECTION CONFIGURATION
// =============================================================================

// Detection thresholds
#define DETECTION_THRESHOLD_DB      65.0f   // Minimum signal level (dB SPL)
#define CONFIDENCE_THRESHOLD        0.75f   // ML model confidence (0-1)
#define DRONE_CLASS_INDEX           1       // Index of "drone" class in model output

// Drone acoustic signature ranges (Hz)
#define DRONE_FREQ_MIN              100     // Minimum frequency of interest
#define DRONE_FREQ_MAX              1000    // Maximum frequency of interest
#define MOTOR_FUNDAMENTAL_MIN       150     // Typical motor fundamental min
#define MOTOR_FUNDAMENTAL_MAX       400     // Typical motor fundamental max

// Alert behavior
#define ALERT_HOLDOFF_MS            2000    // Minimum time between alerts
#define ALERT_DURATION_MS           500     // Buzzer/vibration pulse duration
#define DETECTION_WINDOW_MS         4000    // Rolling window for detection
#define MIN_DETECTIONS_FOR_ALERT    3       // Detections needed in window

// Direction estimation
#define DIRECTION_SMOOTHING         0.3f    // EMA alpha for direction (0-1)
#define MIN_CORRELATION             0.5f    // Minimum cross-correlation for valid TDOA

// =============================================================================
// POWER MANAGEMENT
// =============================================================================

#define BATTERY_LOW_VOLTAGE         6.8f    // 2S low voltage warning (V)
#define BATTERY_CRITICAL_VOLTAGE    6.4f    // 2S critical - shutdown (V)
#define BATTERY_FULL_VOLTAGE        8.4f    // 2S full charge (V)

#define SLEEP_TIMEOUT_MS            0       // 0 = no auto-sleep
#define CPU_FREQ_MHZ                240     // ESP32-S3 frequency

// =============================================================================
// DEBUG CONFIGURATION
// =============================================================================

#define SERIAL_BAUD                 115200
#define DEBUG_ENABLED               true
#define DEBUG_PRINT_FFT             false
#define DEBUG_PRINT_DETECTION       true
#define DEBUG_PRINT_DIRECTION       true

// =============================================================================
// MODEL CONFIGURATION
// =============================================================================

#define MODEL_INPUT_WIDTH           MEL_BINS
#define MODEL_INPUT_HEIGHT          SPEC_TIME_FRAMES
#define MODEL_INPUT_CHANNELS        1
#define MODEL_ARENA_SIZE            (100 * 1024)    // TFLite arena size (bytes)
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
